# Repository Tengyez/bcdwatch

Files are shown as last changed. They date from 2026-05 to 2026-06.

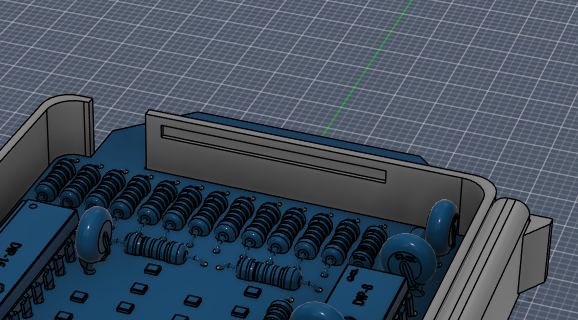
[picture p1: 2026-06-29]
docs/open_inside.png

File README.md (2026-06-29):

# BCD-Wristwatch

A pcb wristwatch using a display of 13 led using binary coded decimal 1248.

## Description

This is a binary clock where the body is made of a circuit board which for me is a nice gimick and a conversation starter.
I specifically design it to need two shift register because if I just use the attmega the pcb surface would be bland and boring.
I also try avoid as many smd as possible except the led because I want the user to be able to debug and fix by just looking a it.
The entire goal of this project isn't to invent a better watch, for me it's a functional art piece customized to my own style.
***The case is optional!
## Getting Started

### Usage

* Press the button once to show the time, hold it 3 seconds to set the time.
* Set the time by press once to increase by one, hold 3 seconds to move to another digit.
* To charge simply plug in the usb-c. (around 5 days per charge for a 100mah battery)
* Green led mean battery ok and red means it's running low.
* You can learn to read the clock from this great tutorial: https://www.wikihow.com/Read-a-Binary-Clock

### Assembling

* The text on the silk screen corresponse to the schematic so soldering should be easy.
* Please flash the attiny before you solder it.
* Solder all the smd first, then add the resistor and capacitor based on the silk screen.
* Hold down those with tape then solder it. Finally solder the attiny, shift-register and power components.
* Connect the lipo battery and put it under the pcb.
* Slide in the wrist strap through the pcb hook.
  
### Firmware

* The code is in C++ made for Attiny85.
* Program it using an ISP via arduino ide.
* !!! Important !!! This can only be done once because we blow the Attiny85 reset fuse.
* Check out the [Firmware](firmware/Firmware.ino)
### ISP programing
* Use any Arduino (but for this example I'm using UNO)
* Requires: jumperwire, breadboard, 10uF capacitor, usb type-B for com to arduino.
* While uploading isp to arduino unplug the capacitor then put it back in after you complete the upload.
* For more information read here: https://www.hackster.io/arjun/programming-attiny85-with-arduino-uno-afb829
* However, the tutorial have a flaw where he connect the capacitor anode to GND DONOT follow it.
```
Attiny85 to Arduino Uno 
pin 1 -> Digital Pin 10
pin 5 -> Digital Pin 11
pin 6 -> Digital Pin 12
pin 7 -> Digital Pin 13
pin 4 -> GND
pin 8 -> 5V
* Add a 10uF capacitor between RESET and GND in arduino to avoid arduino resetting.
```

## Materials

This is the BOM of the pcb, most of them are a through hole component.
For the Lipo and wriststrap you can use whatever components you want.
```
| No. | Component | Qty | cost |
| 1 | 100nF Capacitor | 5 | 20cent
| 2 | 12pF Capacitor | 2 | 8cent
| 3 | 4.7uF Capacitor | 2 | 8cent
| 4 | JST B2B-PH-K-S Connector | 1 | 5cent
| 5 | SMD LED (13 blue, 1 red, 1 green) | 15 | 50cent
| 6 | 330Ω Resistor | 15 | 50cent
| 7 | 10kΩ Resistor | 1 | 5cent
| 8 | 20kΩ Resistor | 1 | 5cent
| 9 | 5.1kΩ Resistor | 2 | 5cent
| 10 | SMD Tactile Switch | 1 | 5cent
| 11 | 74HC595N Shift Register | 2 | 2usd
| 12 | ATtiny85-20PU | 1 | 3usd
| 13 | MCP73831T-2DCI/OT Charger | 1 | 1usd
| 14 | TYPE-C 6P USB Connector | 1 | 1usd
| 15 | 32.768kHz Crystal | 1 | 1usd
| 16 | LiPo Battery ~100mAh *(DNP)* | 1 | 6usd
| 17 | Wrist Strap 20cm *(DNP)* | 1 | 5usd
Total cost: 20.5 usd
```

## PCB Pictures


## With Case


## Schematic 


# Zine Poster
bcd watch zine poster

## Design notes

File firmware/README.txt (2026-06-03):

ISP programing
* Use any Arduino (but for this example I'm using UNO)
* Requires: jumperwire, breadboard, 10uF capacitor, usb type-B for com to arduino.
* While uploading isp to arduino unplug the capacitor then put it back in after you complete the upload.
* For more information read here: https://www.hackster.io/arjun/programming-attiny85-with-arduino-uno-afb829
* However, the tutorial have a flaw where he connect the capacitor anode to GND DONOT follow it.
Attiny85 to Arduino Uno 
pin 1 -> Digital Pin 10
pin 5 -> Digital Pin 11
pin 6 -> Digital Pin 12
pin 7 -> Digital Pin 13
pin 4 -> GND
pin 8 -> 5V
* Add a 10uF capacitor between RESET and GND in arduino to avoid arduino resetting.
* you can test if the test work by uploading an led blinking code first. (connect led to 330Ω to pin5)

#define F_CPU 1000000UL
#include <avr/io.h>
#include <util/delay.h>

int main(void) {
    DDRB |= (1 << PB0);
    while (1) {
        PORTB ^= (1 << PB0);
        _delay_ms(500);
    }
    return 0;
}

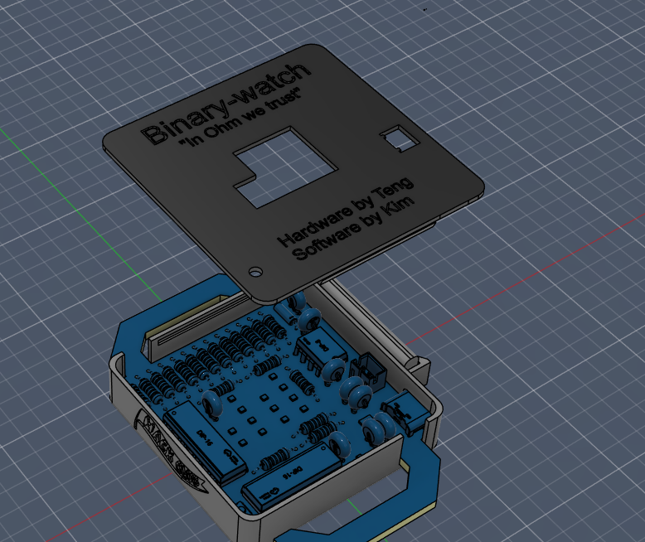
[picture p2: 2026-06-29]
docs/open_top.png

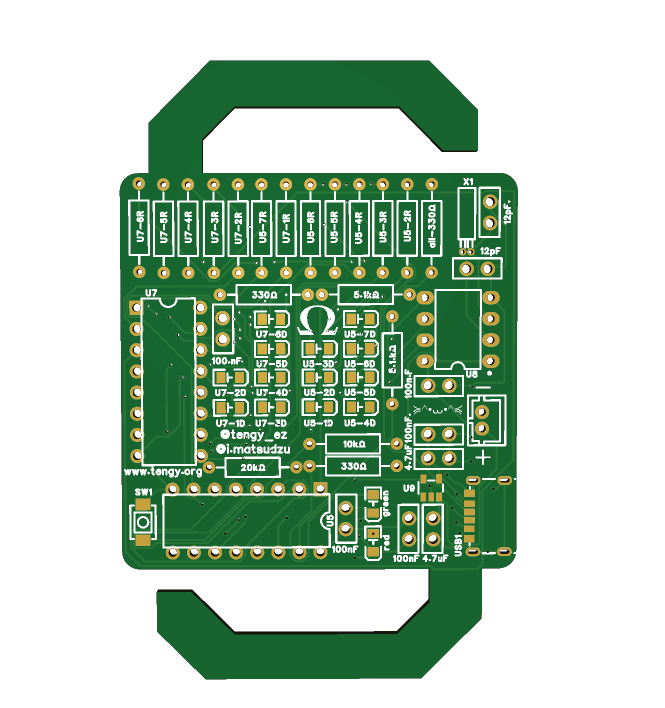
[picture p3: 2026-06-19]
docs/bare-pcb.png

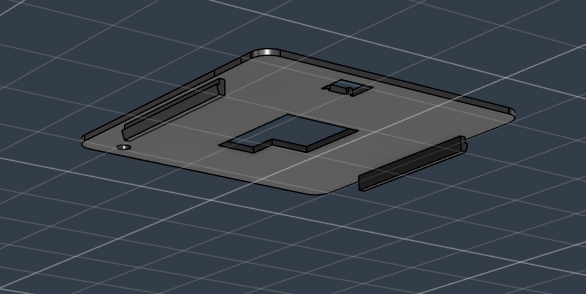
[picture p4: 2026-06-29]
docs/undertop.png

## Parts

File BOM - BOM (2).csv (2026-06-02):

No. | Quantity | Comment | Designator | Footprint | Value | Manufacturer Part | Manufacturer | Supplier Part | Supplier
1 | 5 | 100nF | C6,C7,C8,C13,C16 | CAP-TH_L5.8-W2.4-P2.54-D0.6 | 100nF | CC1H104ZA1ED3F5P1100 | Dersonic(德尔创) | C2832506 | LCSC
2 | 2 | 12pF | C9,C10 | CAP-TH_L5.8-W2.4-P2.54-D0.6 | 12pF | CC1H104ZA1ED3F5P1100 | Dersonic(德尔创) |  | LCSC
3 | 2 | 4.7uF | C14,C15 | CAP-TH_L5.8-W2.4-P2.54-D0.6 | 4.7uF | CC1H104ZA1ED3F5P1100 | Dersonic(德尔创) |  | LCSC
4 | 1 | jumper input | CN1 | CONN-TH_B2B-PH-K-S |  | B2B-PH-K-S-GW | JST | C5251182 | LCSC
5 | 15 | smd led 13blue 1red 1green |  | LED0805-RD |  | TJ-S2012EX8T5ALC2R-A5 | TOGIALED(统佳) | C48689647 | LCSC
6 | 15 | 330Ω | R20,R21,R22,R23,R24,R25,R26,R27,R28,R29,R30,R31,R32,R33,R34 | RES-TH_BD2.3-L6.5-P10.50-D0.5 | 330Ω | MF1/4W-1KΩ±1%T52 | 华星机电 |  | LCSC
7 | 1 | 10kΩ | R36 | RES-TH_BD2.3-L6.5-P10.50-D0.5 | 10kΩ | MF1/4W-1KΩ±1%T52 | 华星机电 |  | LCSC
8 | 1 | 20kΩ | R40 | RES-TH_BD2.3-L6.5-P10.50-D0.5 | 20kΩ | MF1/4W-1KΩ±1%T52 | 华星机电 |  | LCSC
9 | 2 | 5.1kΩ | R41,R42 | RES-TH_BD2.3-L6.5-P10.50-D0.5 | 5.1kΩ | MF1/4W-1KΩ±1%T52 | 华星机电 |  | LCSC
10 | 1 | tactile switch | SW1 | KEY-SMD_L4.0-W3.0-LS4.9-1 |  | HX 3x4x2-2P-1.6N TACTILE SWITCH | hanxia(韩下) | C49234124 | LCSC
11 | 2 | 74HC595N | U5,U7 | DIP-16_L19.8-W6.5-P2.54-LS7.6-BL |  | 74HC595N | HTC | C669328 | LCSC
12 | 1 | ATTINY85-20PU | U8 | PDIP-8_L9.3-W6.4-P2.54-LS7.9-BL-1 |  | ATTINY85-20PU | MICROCHIP(美国微芯) | C965497 | LCSC
13 | 1 | MCP73831T-2DCI/OT | U9 | SOT-23-5_L2.9-W1.6-P0.95-LS2.8-BL |  | MCP73831T-2DCI/OT | MICROCHIP(美国微芯) | C625597 | LCSC
14 | 1 | TYPE-C 6P(073) | USB1 | TYPE-C-SMD_TYPE-C-6P-073 |  | TYPE-C 6P(073) | SHOU HAN(首韩) | C668623 | LCSC
15 | 1 | 32.768kHz | X1 | OSC-TH_BD2.0-P0.70-D0.3 | 32.768kHz | TAXD32768K2BGBBZT2S | YJX(雅晶鑫) | C511702 | LCSC
16 | 1 | lipo-battery(dnp) | not in schematic | square | ≈100mah | - | - | - | -
17 | 1 | wrist-strap(dnp) | not in schematic | any strap | 20cm | - | - | - | -
- | - | - | - | - | - | - | - | - | -
JST connector:
https://www.lcsc.com/search?q=C5251182
SMD LEDs:
https://www.lcsc.com/search?q=C48689647
Tactile switch:
https://www.lcsc.com/search?q=C49234124
74HC595N:
https://www.lcsc.com/search?q=C669328
ATtiny85-20PU:
https://www.lcsc.com/search?q=C965497
MCP73831T:
https://www.lcsc.com/search?q=C625597
USB-C:
https://www.lcsc.com/search?q=C668623
32.768kHz crystal:
https://www.lcsc.com/search?q=C511702
*** Any brand works for watch strap, capacitor, resistor and lipo battery, personally I buy from shoppee and a local electronic market.

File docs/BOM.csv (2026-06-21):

No. | Quantity | Comment | Designator | Footprint | Value | Manufacturer Part | Manufacturer | Supplier Part | Supplier | Link | Cost
1 | 5 | 100nF | C6,C7,C8,C13,C16 | CAP-TH_L5.8-W2.4-P2.54-D0.6 | 100nF | CC1H104ZA1ED3F5P1100 | Dersonic(德尔创) | C2832506 | LCSC |  | $0.20
2 | 2 | 12pF | C9,C10 | CAP-TH_L5.8-W2.4-P2.54-D0.6 | 12pF | CC1H104ZA1ED3F5P1100 | Dersonic(德尔创) |  | LCSC |  | $0.08
3 | 2 | 4.7uF | C14,C15 | CAP-TH_L5.8-W2.4-P2.54-D0.6 | 4.7uF | CC1H104ZA1ED3F5P1100 | Dersonic(德尔创) |  | LCSC |  | $0.08
4 | 1 | jumper input | CN1 | CONN-TH_B2B-PH-K-S |  | B2B-PH-K-S-GW | JST | C5251182 | LCSC | https://www.lcsc.com/search?q=C5251182 | $0.05
5 | 15 | smd led 13blue 1red 1green |  | LED0805-RD |  | TJ-S2012EX8T5ALC2R-A5 | TOGIALED(统佳) | C48689647 | LCSC | https://www.lcsc.com/search?q=C48689647 | $0.50
6 | 15 | 330Ω | R20,R21,R22,R23,R24,R25,R26,R27,R28,R29,R30,R31,R32,R33,R34 | RES-TH_BD2.3-L6.5-P10.50-D0.5 | 330Ω | MF1/4W-1KΩ±1%T52 | 华星机电 |  | LCSC |  | $0.50
7 | 1 | 10kΩ | R36 | RES-TH_BD2.3-L6.5-P10.50-D0.5 | 10kΩ | MF1/4W-1KΩ±1%T52 | 华星机电 |  | LCSC |  | $0.05
8 | 1 | 20kΩ | R40 | RES-TH_BD2.3-L6.5-P10.50-D0.5 | 20kΩ | MF1/4W-1KΩ±1%T52 | 华星机电 |  | LCSC |  | $0.05
9 | 2 | 5.1kΩ | R41,R42 | RES-TH_BD2.3-L6.5-P10.50-D0.5 | 5.1kΩ | MF1/4W-1KΩ±1%T52 | 华星机电 |  | LCSC |  | $0.05
10 | 1 | tactile switch | SW1 | KEY-SMD_L4.0-W3.0-LS4.9-1 |  | HX 3x4x2-2P-1.6N TACTILE SWITCH | hanxia(韩下) | C49234124 | LCSC | https://www.lcsc.com/search?q=C49234124 | $0.05
11 | 2 | 74HC595N | U5,U7 | DIP-16_L19.8-W6.5-P2.54-LS7.6-BL |  | 74HC595N | HTC | C669328 | LCSC | https://www.lcsc.com/search?q=C669328 | $2.00
12 | 1 | ATTINY85-20PU | U8 | PDIP-8_L9.3-W6.4-P2.54-LS7.9-BL-1 |  | ATTINY85-20PU | MICROCHIP(美国微芯) | C965497 | LCSC | https://www.lcsc.com/search?q=C965497 | $3.00
13 | 1 | MCP73831T-2DCI/OT | U9 | SOT-23-5_L2.9-W1.6-P0.95-LS2.8-BL |  | MCP73831T-2DCI/OT | MICROCHIP(美国微芯) | C625597 | LCSC | https://www.lcsc.com/search?q=C625597 | $1.00
14 | 1 | TYPE-C 6P(073) | USB1 | TYPE-C-SMD_TYPE-C-6P-073 |  | TYPE-C 6P(073) | SHOU HAN(首韩) | C668623 | LCSC | https://www.lcsc.com/search?q=C668623 | $1.00
15 | 1 | 32.768kHz | X1 | OSC-TH_BD2.0-P0.70-D0.3 | 32.768kHz | TAXD32768K2BGBBZT2S | YJX(雅晶鑫) | C511702 | LCSC | https://www.lcsc.com/search?q=C511702 | $1.00
16 | 1 | lipo-battery(dnp) | not in schematic | square | ≈100mah | - | - | - | - |  | $6.00
17 | 1 | wrist-strap(dnp) | not in schematic | any strap | 20cm | - | - | - | - |  | $5.00
 |  |  |  |  |  |  |  |  |  | Total | $20.61
- | - | - | - | - | - | - | - | - | - | - | -
*** Any brand works for watch strap, capacitor, resistor and lipo battery, personally I buy from shoppee and a local electronic market.

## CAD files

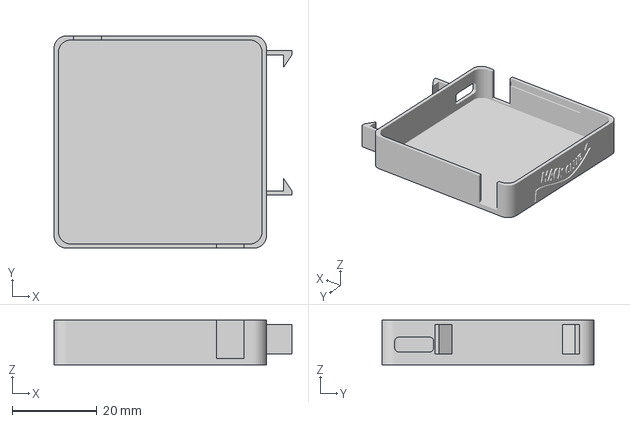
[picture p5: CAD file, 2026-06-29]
3d_print/mainbody.3mf
56.0 x 50.0 x 10.5 mm

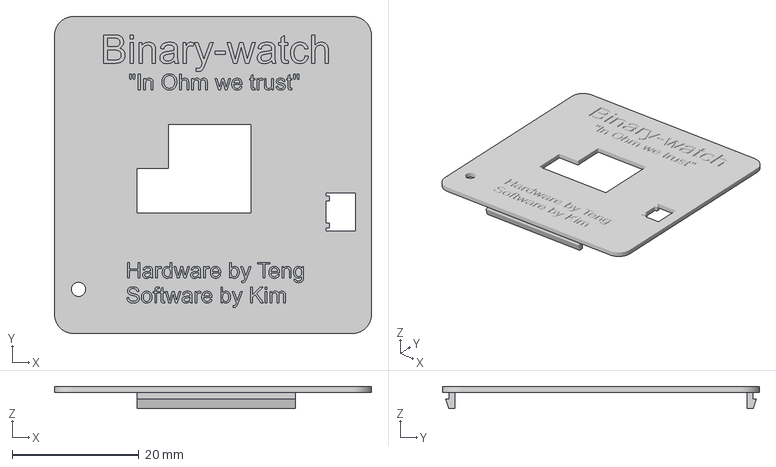
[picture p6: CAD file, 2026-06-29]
3d_print/topcover.3mf
50.0 x 50.0 x 3.50 mm

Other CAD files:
3d_print/mainbody.stl
3d_print/topcover.stl

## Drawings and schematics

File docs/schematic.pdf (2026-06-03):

# VCCGND

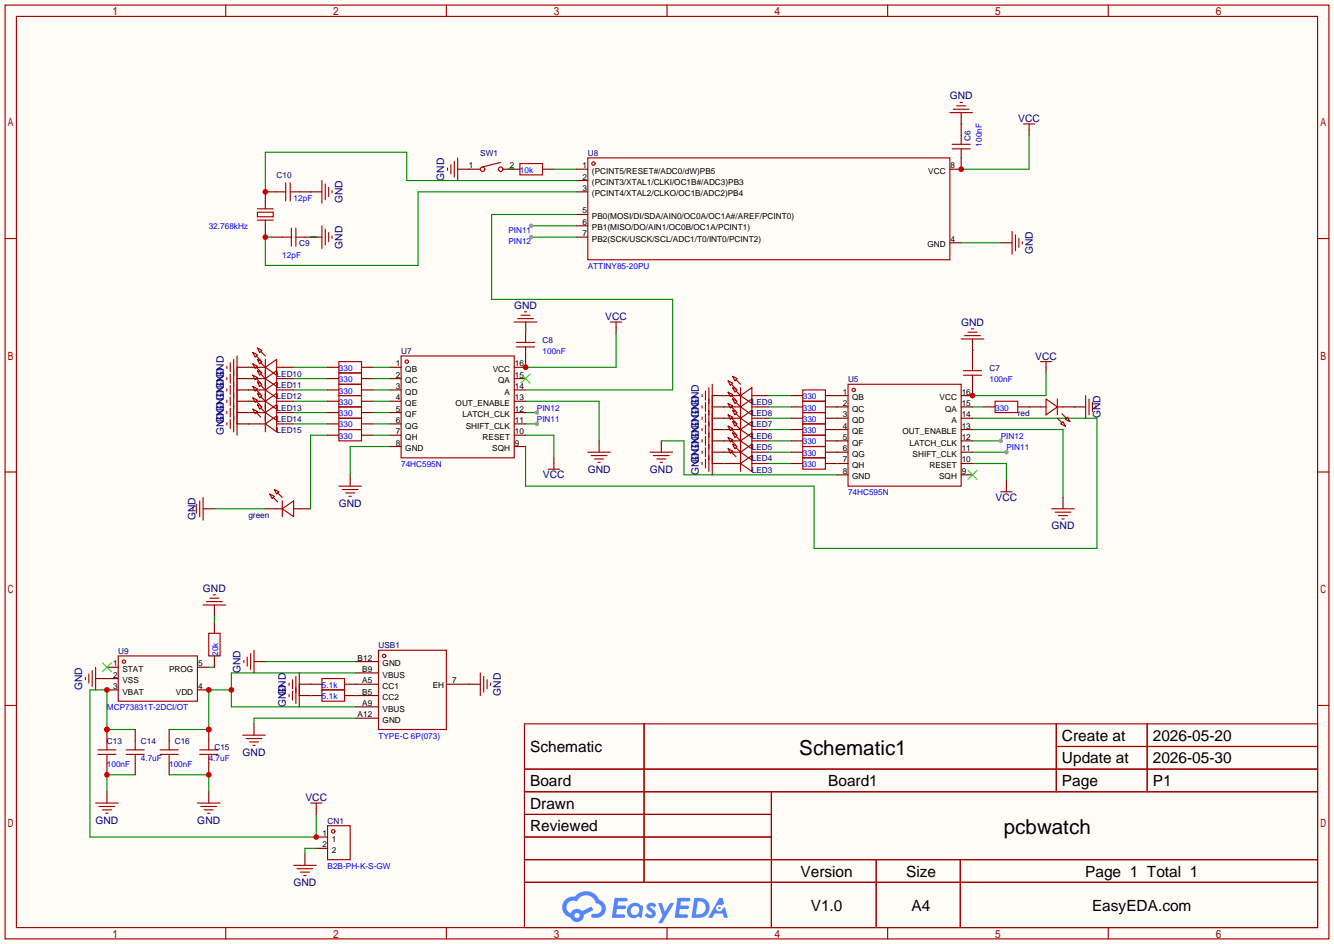
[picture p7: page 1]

PB0(MOSI/DI/SDA/AIN0/OC0A/OC1A#/AREF/PCINT0) 5
PB1(MISO/DO/AIN1/OC0B/OC1A/PCINT1) 6
PB2(SCK/USCK/SCL/ADC1/T0/INT0/PCINT2) 7

GND GND GND

GND GND GND GND GND GND GND

Schematic | Schematic1 | Create at | 2026-05-20

Update at | 2026-05-30

Board | Board1 | Page | P1
Drawn | | pcbwatch
Reviewed

Version | Size | Page 1 Total 1
V1.0 | A4 | EasyEDA.com

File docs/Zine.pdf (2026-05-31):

# BCD-WRISTWATCH

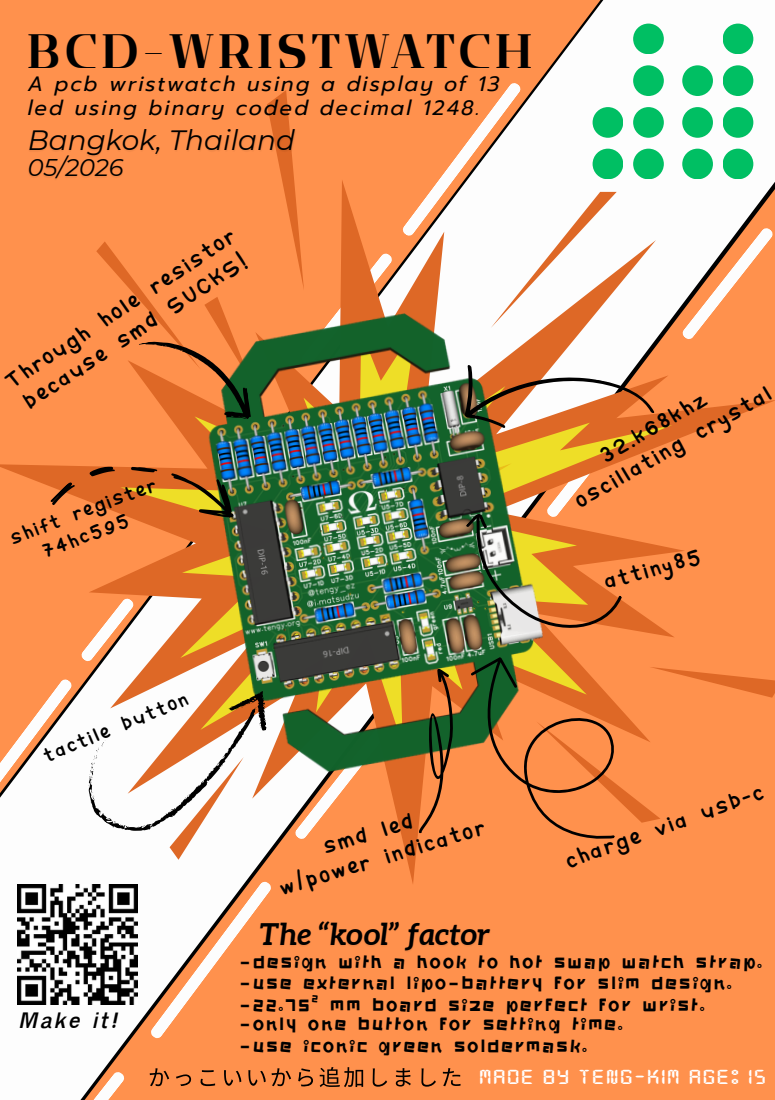
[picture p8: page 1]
Make it!; 32.k68khz; oscillating crystal; shift register 74hc595; tactile button; attiny85; smd led w/power indicator

A pcb wristwatch using a display of 13
led using binary coded decimal 1248.
Bangkok, Thailand

Through hole resistor

because smd SUCKS!

charge via usb-c

The “kool” factor
-design with a hook to hot swap watch st rap.
-use external lipo-battery for slim design.
-22.75 mm board size per fect for wr ist.
-only one button for setting time.
-use iconic green soldermask.
かっこいいから追加しました MADE BY TENG-KIM AGE: 15

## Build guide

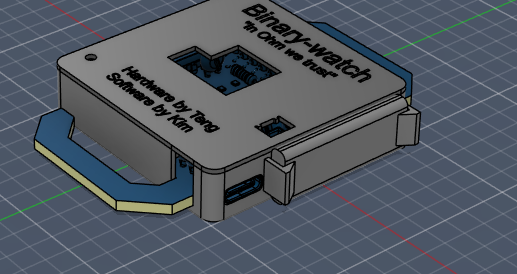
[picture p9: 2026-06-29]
docs/assembled_case_right.png

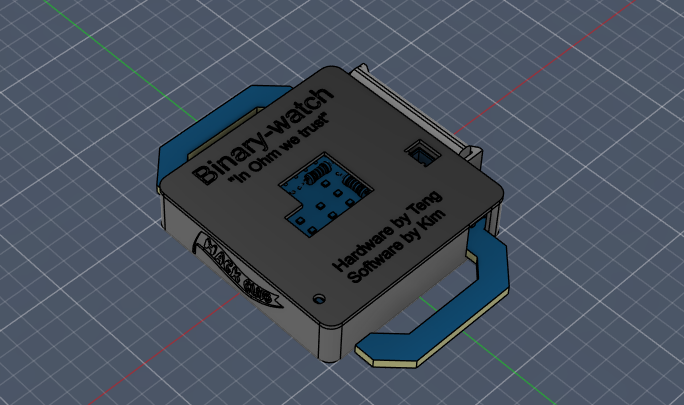
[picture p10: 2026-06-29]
docs/assembled_case.png

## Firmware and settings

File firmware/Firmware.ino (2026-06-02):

#include <avr/io.h>
#include <avr/interrupt.h>
#include <util/delay.h>
#include <util/atomic.h>
#include <avr/eeprom.h>
#include <stdbool.h>

#define DS_PIN  PB0   
#define SH_PIN  PB1   
#define ST_PIN  PB2   

#define EE_MAGIC        ((uint8_t*)0)
#define EE_HOUR         ((uint8_t*)1)
#define EE_MINUTE       ((uint8_t*)2)
#define MAGIC_VAL       0xA5

__attribute__((section(".noinit"))) uint16_t ram_last_press_time;
__attribute__((section(".noinit"))) bool     ram_setting_mode;
__attribute__((section(".noinit"))) uint8_t  ram_current_digit;

volatile uint8_t  g_hour           = 12;
volatile uint8_t  g_minute         = 0;
volatile uint8_t  g_second         = 0;
volatile uint16_t g_ms_counter     = 0;
volatile uint16_t g_blink_counter  = 0;
volatile bool     g_blink_state    = false; 
volatile uint8_t  g_fraction_accum = 0;
volatile uint8_t  g_timeout_seconds = 0;

uint16_t timeTo16Bits(uint8_t hour, uint8_t minute) {
    uint8_t ht = hour   / 10; 
    uint8_t ho = hour   % 10; 
    uint8_t mt = minute / 10; 
    uint8_t mo = minute % 10; 

    uint8_t u7_data = 0; 
    uint8_t u5_data = 0; 

    u7_data |= (ht & 0x03);
    u7_data |= ((ho & 0x0F) << 2);

    u5_data |= (mt & 0x07);
    u5_data |= ((mo & 0x0F) << 3);

    return ((uint16_t)u7_data << 8) | u5_data;
}

void shiftOut16(uint16_t data) {
    PORTB &= ~(1 << ST_PIN); 

    for (int8_t i = 15; i >= 0; i--) {
        if (data & ((uint16_t)1 << i))
            PORTB |=  (1 << DS_PIN);
        else
            PORTB &= ~(1 << DS_PIN);

        PORTB |=  (1 << SH_PIN); 
        PORTB &= ~(1 << SH_PIN);
    }

    PORTB |=  (1 << ST_PIN); 
    PORTB &= ~(1 << ST_PIN);
}

ISR(TIMER0_COMPA_vect) {
    uint8_t ticks = 1;
    
    if (++g_fraction_accum >= 24) {
        g_fraction_accum = 0;
        ticks = 2; 
    }

    g_ms_counter += ticks;
    if (g_ms_counter >= 1000) {
        g_ms_counter -= 1000;
        
        if (++g_second >= 60) {
            g_second = 0;
            if (++g_minute >= 60) {
                g_minute = 0;
                if (++g_hour >= 24) {
                    g_hour = 0;
                }
            }
        }

        if (ram_setting_mode) {
            if (++g_timeout_seconds >= 3) {
                g_timeout_seconds = 0;
                ram_setting_mode = false;
                ram_current_digit = 0;
                eeprom_update_byte(EE_MAGIC,  MAGIC_VAL);
                eeprom_update_byte(EE_HOUR,   g_hour);
                eeprom_update_byte(EE_MINUTE, g_minute);
            }
        }
    }

    if (++g_blink_counter >= 250) { 
        g_blink_state = !g_blink_state;
        g_blink_counter = 0;
    }
}

void timer0_init() {
    TCCR0A = (1 << WGM01);               
    TCCR0B = (1 << CS00);                
    OCR0A  = 31;                         
    TIMSK |= (1 << OCIE0A);              
}

void setup() {
    DDRB |= (1 << DS_PIN) | (1 << SH_PIN) | (1 << ST_PIN);
    
    uint8_t mcusr_bak = MCUSR;
    MCUSR = 0;

    if (eeprom_read_byte(EE_MAGIC) == MAGIC_VAL) {
        g_hour   = eeprom_read_byte(EE_HOUR);
        g_minute = eeprom_read_byte(EE_MINUTE);
    }

    if (mcusr_bak & (1 << EXTRF)) {
        uint16_t current_time_sec = (g_hour * 3600) + (g_minute * 60) + g_second;
        uint16_t time_diff = current_time_sec - ram_last_press_time;
        ram_last_press_time = current_time_sec;

        if (!ram_setting_mode) {
            if (time_diff >= 3) {
                ram_setting_mode = true;
                ram_current_digit = 0; 
            }
        } else {
            g_timeout_seconds = 0; 
            
            if (time_diff >= 3) {
                if (ram_current_digit == 0) {
                    ram_current_digit = 2;
                } else if (ram_current_digit == 2) {
                    ram_current_digit = 3;
                } else if (ram_current_digit == 3) {
                    ram_current_digit = 0;
                }
            } else {
                uint8_t ht = g_hour   / 10;
                uint8_t ho = g_hour   % 10;
                uint8_t mt = g_minute / 10;
                uint8_t mo = g_minute % 10;

                switch (ram_current_digit) {
                    case 0: 
                        ht = (ht + 1) % 3; 
                        if (ht == 2 && ho > 3) ho = 3; 
                        break;
                    case 2: 
                        mt = (mt + 1) % 6; 
                        break;
                    case 3: 
                        mo = (mo + 1) % 10; 
                        break;
                }
                g_hour = ht * 10 + ho;
                g_minute = mt * 10 + mo;
            }
        }
    } else {
        ram_setting_mode = false;
        ram_current_digit = 0;
        ram_last_press_time = 0;
    }

    timer0_init();
    sei();
}

void loop() {
    uint8_t h, m;
    bool blink;
    
    ATOMIC_BLOCK(ATOMIC_FORCEON) {
        h = g_hour;
        m = g_minute;
        blink = g_blink_state;
    }

    uint16_t display_bits = timeTo16Bits(h, m);

    if (ram_setting_mode && !blink) {
        uint16_t mask = 0;
        switch (ram_current_digit) {
            case 0: mask = 0x0300; break;  
            case 2: mask = 0x0007; break;  
            case 3: mask = 0x00F8; break;  
        }
        display_bits &= ~mask;
    }

    shiftOut16(display_bits);
    
    for (volatile uint8_t i = 0; i < 40; i++);
}

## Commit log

2026-05-30 Rename finished bom watch.xlsx to BOM.xlsx
    [BOM.xlsx]
2026-05-30 Revise README with materials and PCB images
    Updated the README to include materials list and PCB pictures.
2026-05-30 Fix typo in materials section of README
    Corrected a typo in the README regarding Lipo and wriststrap components.
2026-05-31 Update README with ISP programming section
    Added instructions for ISP programming using Arduino.
2026-05-31 Rename Untitled spreadsheet - Sheet1.csv to BOM.csv
    [BOM.csv]
2026-06-01 Update requirements for Arduino connection
2026-06-01 Add reference link for ISP programming
    Added a link for more information on programming the ATtiny85 with Arduino.
2026-06-01 Add capacitor recommendation to README
    Add a note about using a 10uF capacitor to prevent Arduino reset issues.
2026-06-01 Update ISP programming instructions in README
    Added note about unplugging capacitor during upload.
2026-06-01 Clarify capacitor connection error in tutorial
    Added a note about a flaw in the tutorial regarding capacitor connections.
2026-06-02 Create BOM-Links.txt with component URLs
    Added various component links for easy reference.
2026-06-02 Update BOM.csv with new components and links
    Added additional components and supplier links to BOM.
    [BOM.csv]
2026-06-02 Rename BOM - BOM (2).csv to BOM.csv
    [BOM.csv]
2026-06-02 Rename BOM (3).csv to BOM.csv
    [BOM.csv]
2026-06-02 Create README with ISP programming instructions
    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
2026-06-03 Rename Screenshot 2026-05-30 182108.png to bare-pcb.png
2026-06-03 Rename Screenshot 2026-05-30 175614.png to pcb-wiring.png
2026-06-19 Add PCB and schematic images to README
    Added a new PCB picture and a schematic image to the README.
2026-06-21 Update BOM with component costs
    Added cost information for each component in the BOM.
2026-06-21 Revise BOM with component links and costs
    Updated BOM to include cost and links for components.
    [BOM.csv]
2026-06-21 Rename Untitled spreadsheet - bom (1).csv to BOM.csv
    [BOM.csv]
2026-06-29 Rename Screenshot 2026-06-29 191538.png to assembled_case.png
2026-06-29 Rename Screenshot 2026-06-29 191544.png to assembled_case_right.png
2026-06-29 Mention optional case in README
    Added a note about the optional case for the binary clock project.
